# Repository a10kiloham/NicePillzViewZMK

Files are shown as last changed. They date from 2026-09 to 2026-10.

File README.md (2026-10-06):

# Nice Pillz View - ZMK config and PCB

## Overview
ZMK configuration and PCB for the Nice Pillz board, a nice!nano based controller for the Kinesis
Advantage, extended with a nice!view display. Based on https://github.com/nol00p/NicePillz.
The keymap follows the Kinesis Advantage legends and targets Windows.

## Hardware
- The PCB in `kicad/` is updated for the display header and the switch LED, see [PCB](#pcb--ordering-from-jlcpcb) below.
- For the original design and the thumb pads, see https://github.com/nol00p/NicePillz
- For the rubber function buttons replacement with PCB for the older Advantage 1, these are excellent: https://github.com/bluelightning32/kinesis-fn
- `housing_stl/niceview_cover.stl` is a printable cover that holds the nice!view in the Kinesis top shell.

<p>
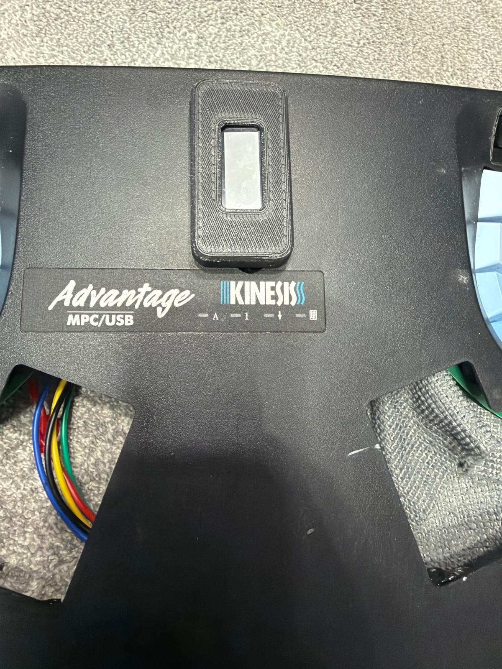
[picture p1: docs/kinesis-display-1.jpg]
nice!view cover fitted in the Kinesis Advantage shell

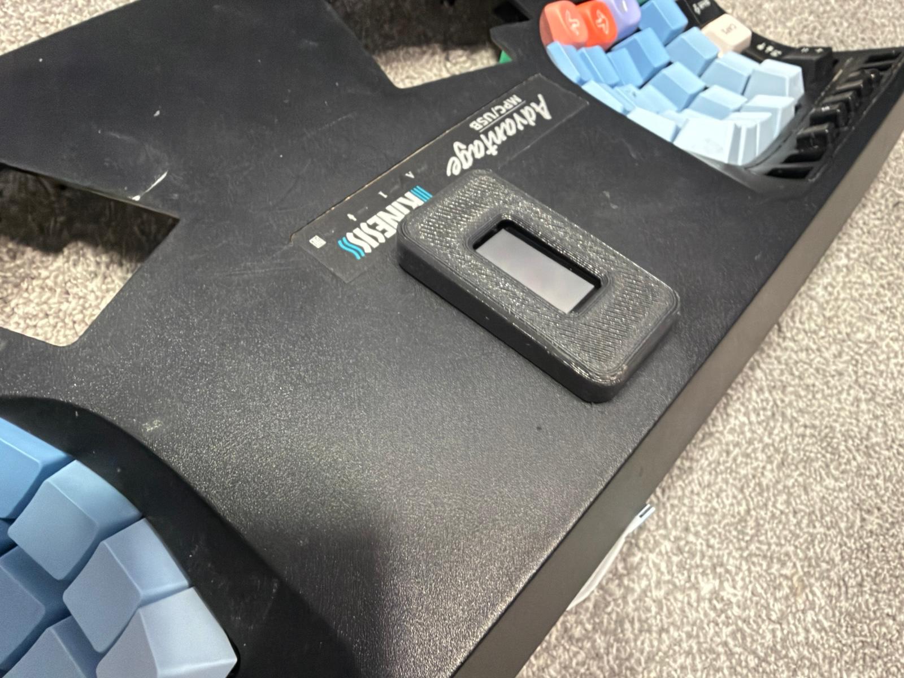
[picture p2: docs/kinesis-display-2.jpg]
nice!view cover, second view

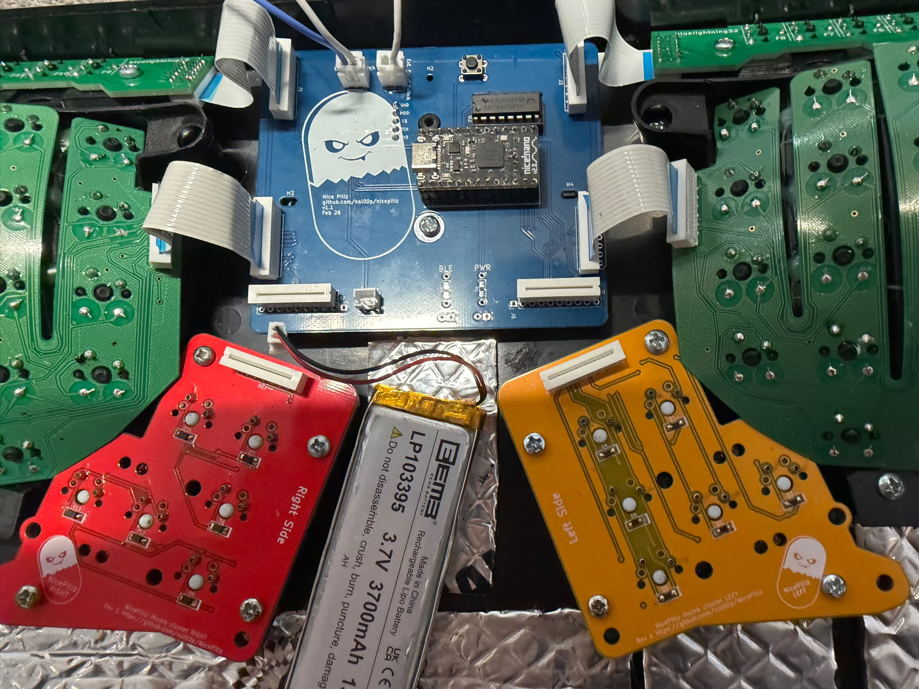
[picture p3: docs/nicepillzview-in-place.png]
Other side

</p>

## Features supported
- [x] ZMK Studio
- [x] nice!view display (vertical): battery/charging, WPM, BT profile, layer, lock indicators
- [x] Leader key
- [x] Caps word
- [x] zmk-helpers
- [x] Layer cycle key
- [x] Macros, with unicode support
- [ ] Combos (supported but not yet tested)

## Quick reference
| Key | Function |
| --- | --- |
| F13 (the Print Screen key) | Unlock ZMK Studio |
| F14 (the Scroll Lock key) | Bluetooth layer, held or tapped before the next key |
| Pause key, right of F14 | Print Screen |
| Keypad key | Layer: steps to the next layer in a loop |
| F14 then 1, 2, 3, 4 | Select Bluetooth profile 1 to 4 |
| F14 then 0 | Toggle the output between Bluetooth and USB |
| F14 then 9, held 3 seconds | Clear the current profile's pairing |
| Program (top right and right thumb) | SYSTEM layer while held |
| Program + Esc or = | Bootloader, for flashing |
| Program + Caps Lock key | Caps Lock |
| Program + left Shift | Leader key |
| Caps Lock key, left side | F5 |
| Key beneath X | Win (GUI) |
| Left thumb, top | Left Ctrl, Alt |
| Right thumb, top | Program, Right Ctrl |
| Left thumb, bottom | Backspace, Delete |
| Right thumb, bottom | Enter, Space |

Notes:

- F13 and F14 are the Print Screen and Scroll Lock positions. Scroll Lock and Pause are not on
  the base layer.
- The Layer key loops through DEFAULT, LOWER, RAISE, FN and KEYPAD, which are dots 1 to 5 on the
  display. SYSTEM and BLUETOOTH are left out of the loop, because they are only meant to be held.
- F13, F14, Print Screen, Layer and Program do the same thing on every layer.
- Left Shift and right Shift are plain Left Shift and Right Shift. Backspace, Delete and Enter are
  plain keys too, so they repeat when held.
- ZMK cannot switch the Bluetooth radio off. F14 then 0 switches the output between Bluetooth and
  USB instead. On battery with USB selected, the keyboard sends nothing.
- F14 then 9 clears only the selected profile. A press shorter than three seconds does nothing.
- LOWER, RAISE and the media-key FN layer are reached with the Layer key.
- The display shows the Bluetooth logo on the left with the profile number beside it at the same
  size. A small tick means connected, a cross means not connected, and no mark means the profile
  is free and advertising.

### Label for the bottom of the keyboard
`docs/bottom-label.txt` fits a 3 x 3 inch label. Print it in a monospace font at 8 pt.

```
NICE PILLZ VIEW - QUICK REFERENCE

TOP RIGHT  F13 Unlock Studio |
  F14 BT | PrtSc | Layer | Program

BLUETOOTH  hold F14 +
  1 2 3 4   select device 1-4
  0         Bluetooth <-> USB
  9 (3 s)   forget this device

SYSTEM     hold Program +
  Esc or =  flash mode (NICENANO)
  Caps key  Caps Lock

LAYER  next layer, loops 1 to 5
  Caps Lock key = F5, under X = Win
  L thumb: Ctrl Alt / Bksp Del
  R thumb: Prog Ctrl / Enter Spc

EDIT KEYS  https://zmk.studio
github.com/a10kiloham/NicePillzViewZMK
```

## Keymap (Windows)
`config/nicepillz.keymap`. The base layer follows the key legends, with these choices:

- Caps Lock position is **F5**. Left Shift is Left Shift and right Shift is Right Shift, both plain keys.
- The letter rows are plain keys, no home-row mods. The key beneath X, left of the Left arrow, is
  **Win**.
- Thumbs: Ctrl, Alt | Program, Ctrl on top; Backspace, Delete | Enter, Space on the big keys, all
  plain keys.
- Top right keys after F12: **Studio unlock** (F13), **Bluetooth** (F14), **Print Screen**,
  **Layer**, **Program**, the same on every layer. Layer steps to the next layer in a loop:
  DEFAULT, LOWER, RAISE, FN, KEYPAD.
- KEYPAD is the numpad layer
  (7 8 9 on U I O, 4 5 6 on J K L, 1 2 3 on M , ., 0 and . on Up/Down, Enter on / and the right
  thumb Enter, Num Lock on 7). The digits follow the Num Lock state, as on any numpad.
  **Program** held = SYSTEM, on both the top right key and the right thumb key.
- **F14** (the Scroll Lock key) is the Bluetooth key, held or tapped before the next key:
  **1-4** select the Bluetooth profile, **0** toggles the output between Bluetooth and USB,
  **9** held for 3 seconds clears the current profile's bond.
- LOWER: F1/F2 previous/next virtual desktop, F3 task view, F4 new desktop, F8 input language,
  F9/F10 move window to the left/right monitor, F11 show desktop, F12 close desktop; arrows on
  H J K L; Ctrl+A/Z/X/C/V on the left hand.
- RAISE: Win+Left/Down/Up/Right on H J K L (snap, restore, maximise, snap), Win+M on U,
  Ctrl+= / Ctrl+- zoom on the number row, ( ) [ ] { } on E R.
- FN: F6 mute, F7 volume down, F8 volume up, F9 previous, F10 play/pause, F11 next, F12 stop.
- SYSTEM (hold Program): **ESC or = = bootloader** (flashing mode), F1-F4 select Bluetooth
  profiles 1-4, F8 clears the current profile's bond, the Caps Lock key is **Caps Lock**, left
  Shift is the **leader** key.

### ZMK Studio
Open [zmk.studio](https://zmk.studio) in Chrome or Edge (Web Serial; Firefox does not work) or the
Studio desktop app, with the keyboard plugged in over USB and running normally, and choose the
`NicePillz` serial device. The keyboard starts locked: press **F13** to unlock, then the keymap
becomes editable. Program+Esc is *not* the Studio key, it reboots into the bootloader for
flashing, and Studio cannot connect while the `NICENANO` drive is showing.
- Leader sequences (hold Program, tap left Shift, then type the sequence): `4` euro sign,
  `D 1`/`D 2` previous/next desktop, `W 1`/`W 2` move window left/right. Unicode macros (accented letters) type through [WinCompose](https://github.com/samhocevar/wincompose),
  which must be installed on the PC.

Keys edited in ZMK Studio are stored on the keyboard and override this file. Flashing a firmware
whose keymap file has changed discards those stored edits automatically on the first boot
(`boards/shields/nicepillz/keymap_rev.c`), so the flashed keymap is always the default. Flashing
the same keymap again keeps the Studio edits; *Restore Stock Settings* in Studio removes them.

## Battery level
Battery reporting is enabled so the level is visible in the OS. Bluetooth and power status update
too for a better experience.

## Display (nice!view)
The board carries a nice!view (Sharp 160x68 memory LCD), mounted vertically with the header pins
at the bottom. The status screen (`boards/shields/nicepillz/view_draw.c`) is drawn upright and
rotated into the panel, top to bottom:

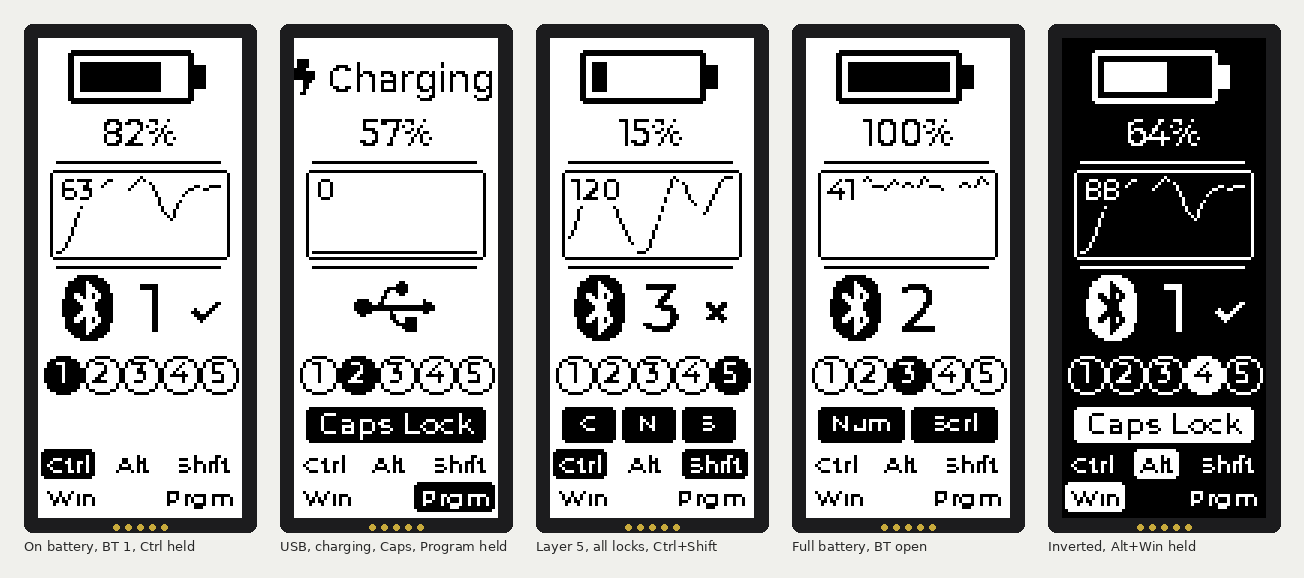
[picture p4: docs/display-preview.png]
display preview


1. **Battery** - a battery-shaped gauge plus the percentage. On USB power the gauge is replaced by
   a lightning bolt and the word *Charging*.
2. **Words per minute** - a graph of the last 24 samples (one every 5 s, so two minutes of
   history, auto-scaled) with the current value in the corner (`CONFIG_NICEPILLZ_WPM_INTERVAL_MS`).
3. **Output** - a Bluetooth logo on the left with the active profile number beside it at the
   same size, then a small tick (connected) or cross (bonded but not connected); a USB symbol
   when USB is the selected output.
4. **Layer** - five numbered dots; the filled one is the highest active layer (1-5).
5. **Lock indicators** - *Caps Lock*, *Num Lock*, *Scrl Lock* boxes in a row, only the active
   ones; they use the host's HID lock state.
6. **Modifiers** - *Ctrl Alt Shift Win Prgm* along the bottom edge; each lights up while the key
   is held. *Prgm* is the Program key, i.e. the SYSTEM layer
   (`CONFIG_NICEPILLZ_PROGRAM_LAYER`).

Options (`boards/shields/nicepillz/Kconfig.defconfig`, override in `boards/shields/nicepillz/nicepillz.conf`):
- `CONFIG_ZMK_DISPLAY=n` disables the display entirely.
- `CONFIG_NICEPILLZ_DISPLAY_INVERTED=y` draws white on black.
- `CONFIG_NICEPILLZ_DISPLAY_LANDSCAPE=y` uses the landscape layout: the picture is turned 90
  degrees clockwise, for a display mounted with the header pins on the right. The same
  elements are rearranged for the 160x68 shape: battery, WPM graph and output on top, layer dots
  and modifiers bottom left, lock indicators bottom right.

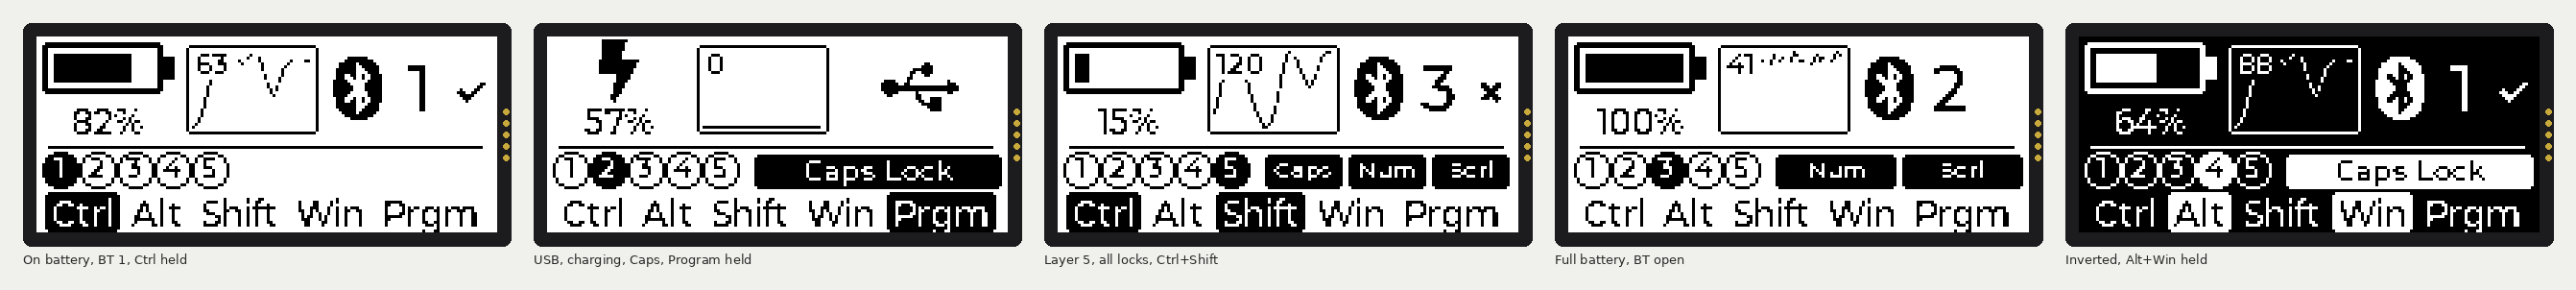
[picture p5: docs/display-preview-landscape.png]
landscape display preview


`tools/preview/build.sh` compiles the real drawing code against LVGL on the host and writes
`docs/display-preview.png`, so layout changes can be checked without flashing.

Wiring: the display shares the SPI bus with the 74HC595 column driver. SCK = P0.11 (D7),
MOSI = P0.24 (D5), display CS = P1.01, powered from the nice!nano VCC pin (switched off in deep
sleep together with the shift register). On v10 boards the J9 header is in the nice!view's own pin
order (CS, GND, 3V3, SCK, MOSI, top to bottom) so the display plugs straight in. v9 boards have J9
as GND, MOSI, CS, SCK, 3V3 and need the display wired pin by pin.

## LEDs and sleep
- **PWR** (D1): on while the board is awake, driven by the spare 74HC595 output (P1.01 is the
  display chip select). Slow flash after 5 min idle, off in deep sleep.
- **BLE** (D2): on while the active Bluetooth profile is connected, off when idle or asleep.
- **Switch LED** header (v10): powers the LED inside an illuminated power switch whenever the board
  has power, see [PCB](#pcb--ordering-from-jlcpcb).

Sleep after 5 min idle: any key resumes. Deep sleep after 20 min: press the Esc key (0,0) to wake.

## PCB / ordering from JLCPCB
`kicad/nice_pillz_niceview_v10.kicad_pcb` is the board (KiCad 10). Ready-to-upload fabrication
files, exported with `kicad-cli` from the committed board (DRC: 0 unconnected items), are in
`kicad/jlcpcb/` and attached to the [v10 release](https://github.com/a10kiloham/NicePillzViewZMK/releases/tag/v10):

- `nice_pillz_niceview_v10_jlcpcb.zip` - upload this as-is to JLCPCB (2 layers, 1.6 mm).
- `gerbers/` - the same files unzipped: copper, mask, paste, silkscreen, board outline (Protel
  extensions), Excellon drills split into PTH / NPTH, and a drill map.

## 

Changes in v10 (silkscreen v1.1) compared with the v9 boards already made:

- **J9 display header** is ordered CS, GND, 3V3, SCK, MOSI to match the nice!view (see Display above).
  Pad numbers and nets are unchanged, so the schematic still matches; only the pad positions inside
  the footprint instance moved (re-importing the footprint from the library would undo this).
- **Switch LED header** replaces the external reset terminal at the top of the board (same two holes).
  It is a 2-pin 2.54 mm header for the LED inside an illuminated power switch: the square pin (marked
  `+`) is the LED anode, fed from the switched 3.3 V rail through **R3** next to it; the round pin is
  GND. Fit R3 to suit the LED: 330 R for red/green/yellow (about 4 mA), 100 R for blue/white. The
  LED is on whenever the keyboard is powered: off when the power switch is off, off in deep sleep
  (the firmware cuts the 3.3 V rail), and on while charging over USB even with the switch off. The
  onboard reset push button is unchanged; there is no longer a terminal for an external reset.
- D1/D2 are labelled LED_PWR / LED_BLE on the fab layer.

## Hardware bill of materials
Mostly common parts and a bit of soldering.

| Position | Part | Qty | Notes |
| --- | --- | --- | ----- |
| J1-J4, J7, J8 | Molex 39-53-2135, 13-way | 6 | [Mouser](https://eu.mouser.com/ProductDetail/Molex/39-53-2135?qs=cm0cgiBciNYI3jeMaEn0Ng%3D%3D) |
| J5, J6 | 1x10 pin header, 2.54 mm | 2 | |
| J9 | nice!view | 1 | v10: plugs onto the header; v9: wire pin by pin |
| | JST-EH 5-pin connector | 2 | display lead |
| | Mill Max 0305 sockets
| U1 | nice!nano v2 | 1 | |
| U2 | 74HC595 | 1 | [Amazon](https://www.amazon.fr/dp/B093Y2MQGV) |
| U2 | Mill Max style connected sockets | 1 | |
| D1, D2 | LED (PWR, BLE) | 2 | [Amazon](https://www.amazon.fr/dp/B005Q2MZ4Q) |
| R1, R2 | 4.7 k resistor | 2 | sets LED brightness, smaller = brighter (1 k is clearly visible at 3.3 V) |
| R3 | 330 R (red/green/yellow) or 100 R (blue/white) | 1 | switch LED series resistor |
| Battery, Ext. PWR Switch | 2-pin screw terminal, 2.54 mm | 2 | v9 boards have a third one for an external reset |
| Switch LED | 1x2 pin header, 2.54 mm | 1 | v10 only |
| | 6 mm tactile reset button | 1 | |
| | Illuminated power switch | 1 | Adafruit; LED leads go to the Switch LED header on v10 |
| | 3.7 V LiPo battery, 2000 mAh | 1 | [Amazon](https://www.amazon.fr/dp/B08214DJLJ) |
| | USB-C panel mount extension | 1 | [AliExpress](https://fr.aliexpress.com/item/1005009401577622.html) |
| | Display cover, 3D printed | 1 | `housing_stl/niceview_cover.stl` |

## 3D Printed Parts
Thanks to `happy panda` for their design here: https://www.printables.com/model/1622734-kinesis-advantage-thumb-millmax-mod
Remixed here if you're using stabilizers: https://www.printables.com/model/1842360-kinesis-thumb-cluster-pcb-replacement-millz-mod-co

## Assembly
A small hot plate (Miniware MHP30 or a cheaper clone) makes the SMD parts much easier.
LED orientation: with the LEDs facing up, the arrow points to the left across the two pads.

## Firmware
GitHub Actions builds the firmware on every push (`build.yaml`). Prebuilt images for the
nice!nano v2 are in `firmware/` and on the release page:

- `nicepillz_nice_nano_v2.uf2` - black on light (default).
- `nicepillz_nice_nano_v2_inverted.uf2` - light on black display (`CONFIG_NICEPILLZ_DISPLAY_INVERTED=y`).
- `nicepillz_nice_nano_v2_landscape.uf2` - landscape display, black on light (`CONFIG_NICEPILLZ_DISPLAY_LANDSCAPE=y`).
- `nicepillz_nice_nano_v2_landscape_inverted.uf2` - landscape display, light on black.
- `settings_reset_nice_nano_v2.uf2` - erases every stored setting: Bluetooth pairings, the keymap
  saved by ZMK Studio, and the selected output.
- `nicepillz_nice_nano_v2_usblog.uf2` and `nicepillz_nice_nano_v2_landscape_usblog.uf2` - the
  portrait and landscape firmware with debug logging over USB, for finding out what the keyboard
  thinks it sent (see below). Slower, use only to debug.

Flash by double-tapping reset and copying the file to the `NICENANO` drive.

To reset the settings entirely, flash `settings_reset_nice_nano_v2.uf2` first. The keyboard does
not type while it is loaded. Then double-tap reset again and flash the normal firmware. Remove the
keyboard from each computer's Bluetooth device list before pairing again.

### Debug logging over USB
Flash `nicepillz_nice_nano_v2_usblog.uf2` (portrait) or `nicepillz_nice_nano_v2_landscape_usblog.uf2`
(landscape), built with `-S zmk-usb-logging` and `CONFIG_ZMK_LOG_LEVEL_DBG=y`. The keyboard then shows up as two serial ports: one is ZMK Studio,
the other streams the log. Open the log port at any baud rate, for example in PowerShell:

```
[System.IO.Ports.SerialPort]::GetPortNames()      # find the new COM port, try each
$p = New-Object System.IO.Ports.SerialPort COM5, 115200; $p.Open()
while ($true) { $l = $p.ReadLine(); if ($l -match "keycode|hold-tap|hold_tap") { $l } }
```

Every key press and release appears as `hid_listener_keycode_pressed ... keycode 0x..`:
0xE0 to 0xE7 are the modifier keys (E0 Left Ctrl, E1 Left Shift, E2 Left Alt, E3 Left Win, E4 to
E7 the right-hand ones). The hold-tap lines name the key position of the few remaining hold-taps
(the Bluetooth layer's 9 key) and say whether they were decided as a hold or a tap, and why.

## Credits
- https://github.com/nol00p/ZMK-NicePillz
- https://github.com/dcpedit/pillzmod
- https://github.com/masters3d/zmk-config-pillzmod-nicenano
- https://github.com/urob/zmk-leader-key
- https://github.com/urob/zmk-helpers

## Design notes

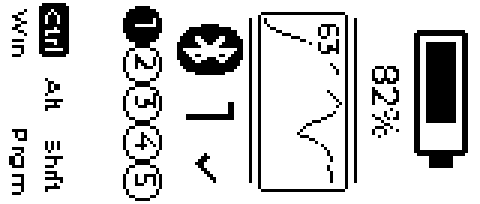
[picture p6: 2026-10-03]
docs/display-panel-raw.png

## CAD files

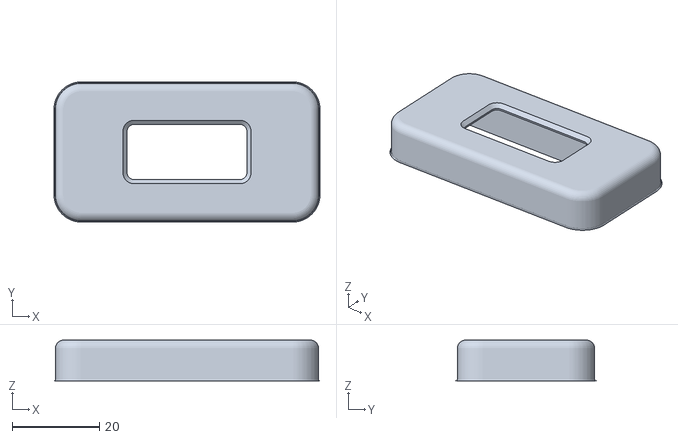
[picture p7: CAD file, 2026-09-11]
housing_stl/niceview_cover.stl
61.1 x 32.2 x 9.39

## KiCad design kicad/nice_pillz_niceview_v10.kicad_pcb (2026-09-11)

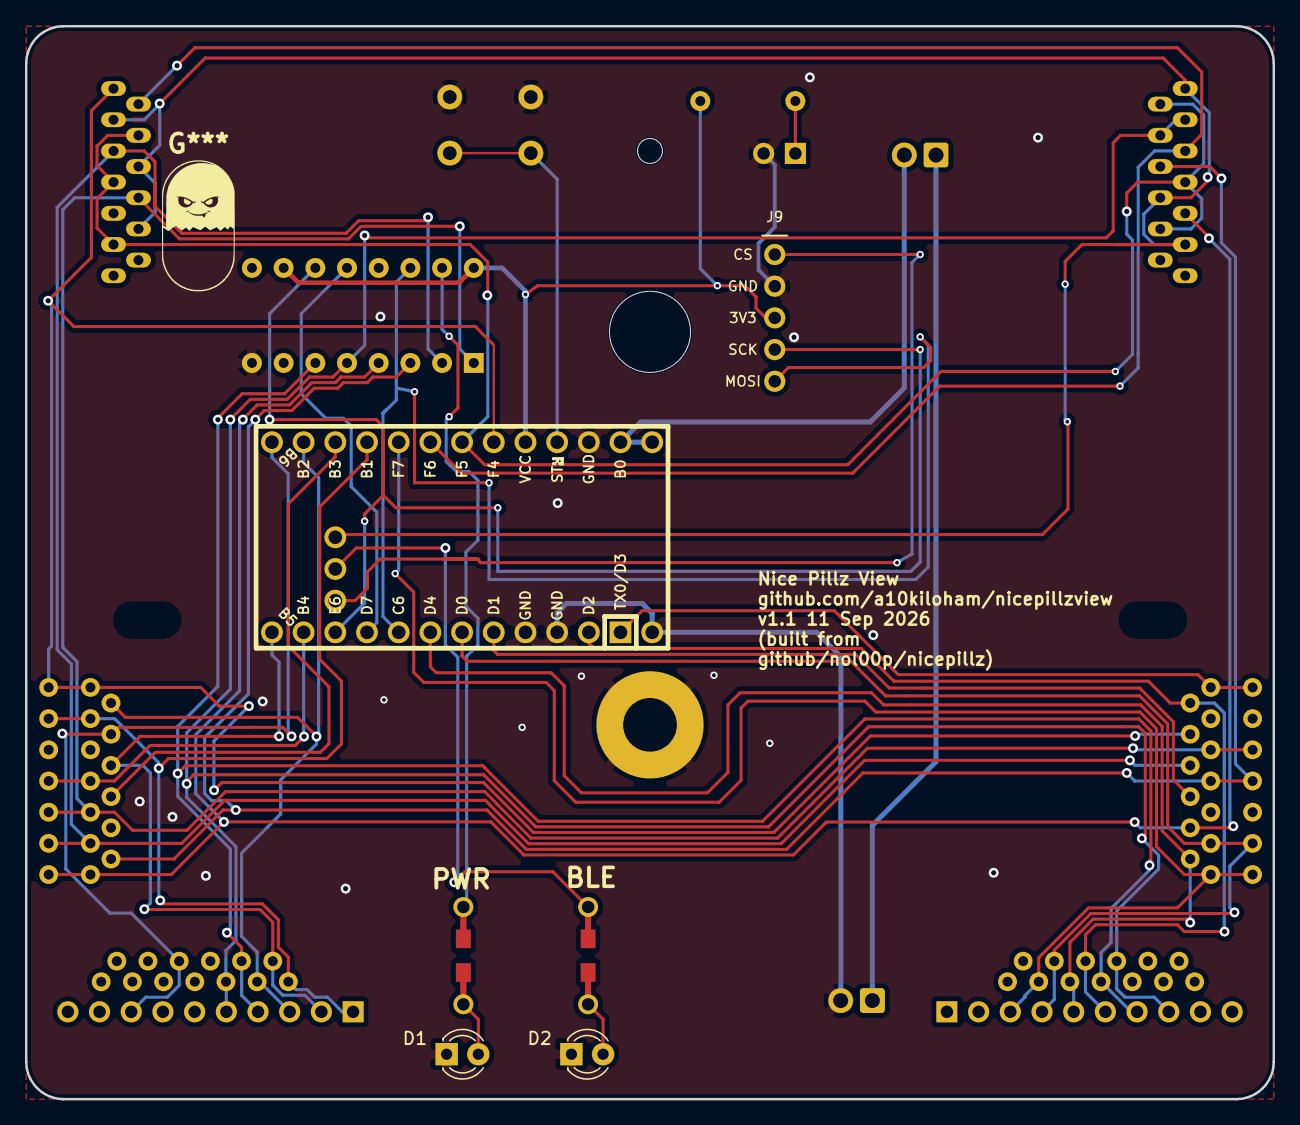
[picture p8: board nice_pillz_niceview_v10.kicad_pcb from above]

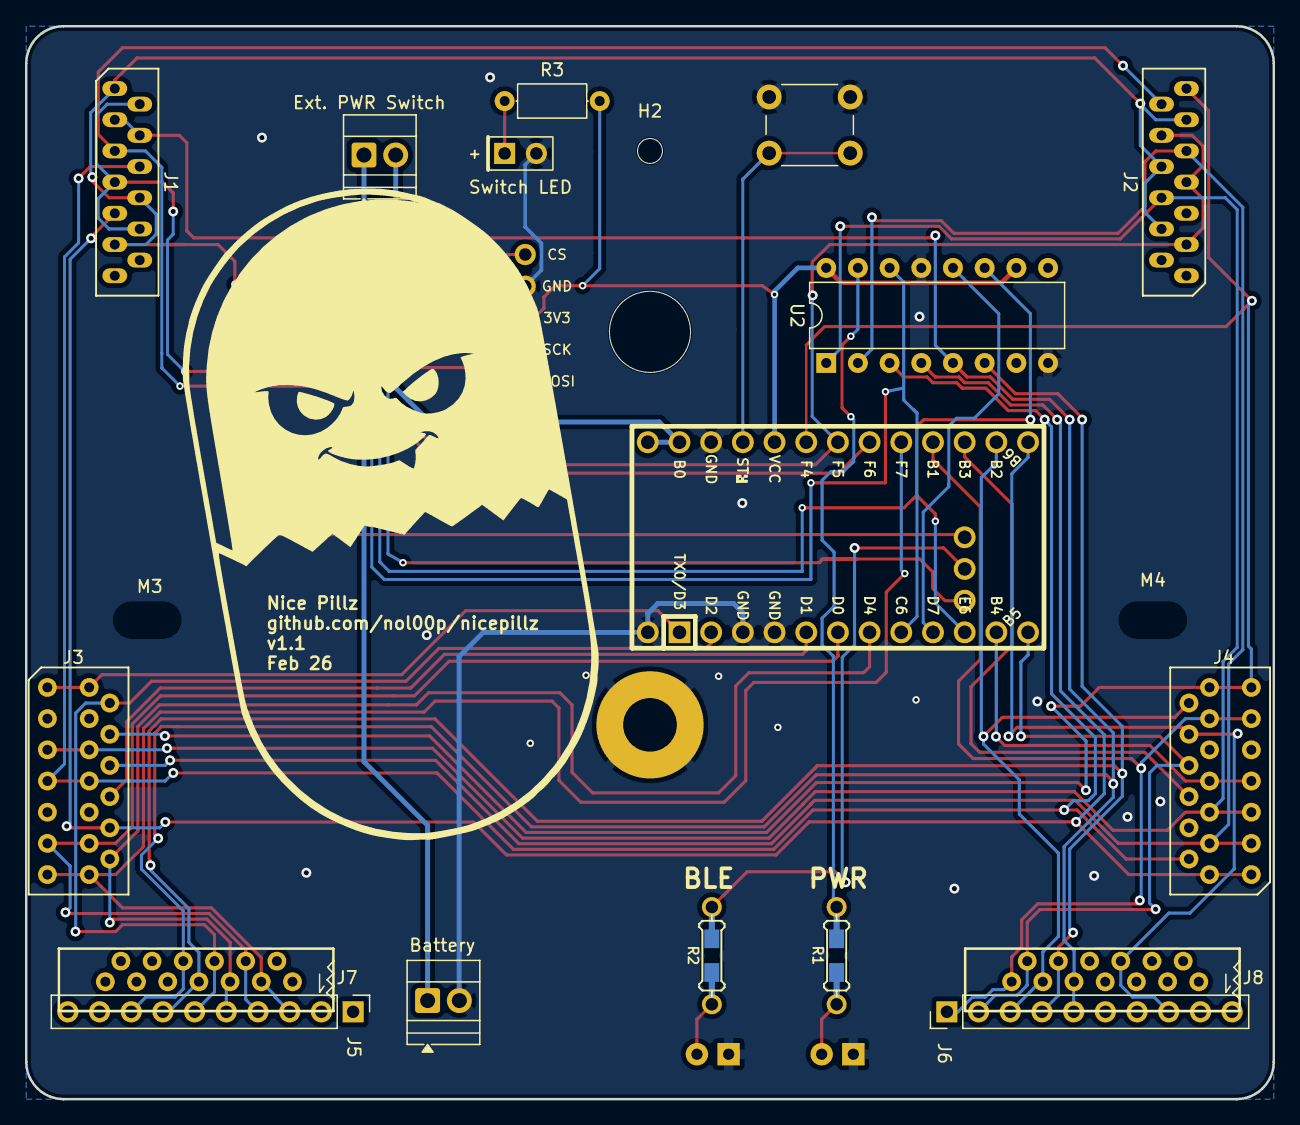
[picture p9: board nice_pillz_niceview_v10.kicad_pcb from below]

Board: 2 copper layers, 100.0 x 86.0 mm, 24 parts (20 on the bottom side), 35 nets.

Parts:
Battery: TerminalBlock_Xinya_XY308-2.54-2P_1x02_P2.54mm_Ho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; TerminalBlock_Xinya_XY308-2.54-2P_1x02_P2.54mm_Horizontal
D1: LED_PWR; LED_D3.0mm
D2: LED_BLE; LED_D3.0mm
Ext. PWR Switch: TerminalBlock_Xinya_XY308-2.54-2P_1x02_P2.54mm_Ho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; TerminalBlock_Xinya_XY308-2.54-2P_1x02_P2.54mm_Horizontal
H1: mounting pad; MountingHole_4.3mm_M4_Pad
H2: mounting pad; MountingHole_2mm
J1, J2: Conn_01x13; Molex_0039532135
J3, J4: Conn_01x13; Molex_039532134
J5, J6: Conn_01x10; Pin_Header_Straight_1x10_Pitch2.54mm
J7, J8: Conn_01x13; 39-53-2135
J9: NiceView; NiceView_1x05_P2.54mm_V
M1: MountingHole_6.4mm_M6
M3, M4: MountingHole_4.3mm_M4
R1, R2: R_US; Resistor-Hybrid
R3: 330R; R_Axial_DIN0207_L6.3mm_D2.5mm_P7.62mm_Horizontal
Switch LED: PinHeader_1x02_P2.54mm_Vertical
U1: nice!nanov2; nice_nano_v2
U2: 74HC595; DIP-16_W7.62mm

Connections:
+5V: J9.5, R3.2, U1.21 (VCC), U2.10 (~SRCLR), U2.16 (VCC)
/COL_0: J2.13, J3.4, J4.13, U1.20 (A3/PF4)
/COL_1: J2.6, J3.5, J4.5, U2.1 (QB)
/COL_2: J2.9, J3.6, J4.3, U2.2 (QC)
/COL_3: J1.6, J3.7, J4.2, U2.3 (QD)
/COL_4: J1.9, J3.10, J4.1, U2.4 (QE)
/COL_5: J1.3, J1.4, J5.8, J6.5, J7.8, J8.9, U2.5 (QF)
/COL_6: J5.7, J6.4, J7.7, J8.10, U2.6 (QG)
/LATCH: U1.9 (6/PD7), U2.12 (RCLK)
/LED_CAPS_LOCK: J9.3, U1.26 (D5)
/LED_NUM_LOCK: R2.2, U1.27 (C7)
/PWR_LED: R1.2, U2.15 (QA)
/ROW_0: J4.6, U1.15 (14/PB3)
/ROW_1: J4.7, U1.11 (8/PB4)
/ROW_2: J4.8, J6.2, J8.12, U1.12 (9/PB5)
/ROW_3: J4.10, J6.8, J8.6, U1.13 (10/PB6)
/ROW_4: J4.11, J6.1, J8.13, U1.16 (15/PB1)
/ROW_5: J4.12, J6.3, J8.11, U1.14 (16/PB2)
/ROW_6: J3.13, J5.3, J7.3, U1.17 (A0/PF7)
/ROW_7: J3.11, J5.4, J7.4, U1.6 (3/PD0)
/ROW_8: J3.12, J5.5, J7.5, U1.7 (4/PD4)
/ROW_9: J3.2, J5.6, J7.6, U1.2 (RX1/PD2)
/ROW_10: J3.1, U1.1 (TX0/PD3)
/ROW_11: J3.8, U1.5 (2/PD1)
/ROW_12: J1.5, J2.12, U1.18 (A1/PF6)
/ROW_13: J1.1, J1.8, J1.11, J2.4, J2.8, J2.11, U1.28 (F1)
/ROW_14: J1.2, J1.7, J1.10, J2.3, J2.7, J2.10, U1.19 (A2/PF5)
/SPI_MOSI: J9.2, U1.8 (5/PC6), U2.14 (SER)
/SPI_SCK: J9.4, U1.10 (7/PE6), U2.11 (SRCLK)
/SW_LED: R3.1, Switch LED.1
BAT: Ext. PWR Switch.2, U1.24 (B0)
BAT+: Battery.1, Ext. PWR Switch.1
GND: Battery.2, D1.1 (K), D2.1 (K), H1.1, J9.1, Switch LED.2, U1.3 (GND), U1.4 (GND), U1.23 (GND), U2.8 (GND), U2.13 (~OE)
unnamed: D1.2 (A), R1.1
unnamed: D2.2 (A), R2.1

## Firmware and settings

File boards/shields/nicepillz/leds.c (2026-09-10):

/*
 * Status LEDs for the Nice Pillz.
 *
 *   led_0 / led-caps : power LED, driven by the 74HC595 output QA
 *   led_1 / led-num  : BLE LED, driven directly by P1.02
 *
 * The 74HC595 is reached over SPI, and its GPIO driver refuses to run from
 * interrupt context (it returns -EWOULDBLOCK). All LED writes are therefore
 * funnelled through a single work item on the system work queue; the idle
 * blink timer only flips a phase flag and queues that work.
 *
 * Behavior:
 *   active : power LED on, BLE LED mirrors the active profile connection
 *   idle   : power LED slow blink (1s on / 2s off), BLE LED off
 *   sleep  : both off
 */

#include <zephyr/device.h>
#include <zephyr/devicetree.h>
#include <zephyr/drivers/led.h>
#include <zephyr/kernel.h>
#include <zephyr/init.h>
#include <zephyr/logging/log.h>

#include <zmk/ble.h>
#include <zmk/activity.h>
#include <zmk/event_manager.h>
#include <zmk/events/ble_active_profile_changed.h>
#include <zmk/events/activity_state_changed.h>

LOG_MODULE_REGISTER(nicepillz_leds, CONFIG_ZMK_LOG_LEVEL);

#define LED_GPIO_NODE_ID DT_COMPAT_GET_ANY_STATUS_OKAY(gpio_leds)

#define LED_PWR DT_NODE_CHILD_IDX(DT_ALIAS(led_caps))
#define LED_BLE DT_NODE_CHILD_IDX(DT_ALIAS(led_num))

/* Idle blink timing */
#define IDLE_BLINK_ON_MS 1000
#define IDLE_BLINK_OFF_MS 2000

static const struct device *led_dev = DEVICE_DT_GET(LED_GPIO_NODE_ID);

static enum zmk_activity_state activity = ZMK_ACTIVITY_ACTIVE;
static bool blink_phase_on;

static void set_led(uint32_t led, bool on) {
    int ret = on ? led_on(led_dev, led) : led_off(led_dev, led);
    if (ret < 0) {
        LOG_WRN("Failed to set LED %u: %d", led, ret);
    }
}

/* --- Apply the LED state for the current activity/BLE state --- */

static void led_update_handler(struct k_work *work) {
    switch (activity) {
    case ZMK_ACTIVITY_ACTIVE:
        set_led(LED_PWR, true);
        set_led(LED_BLE, zmk_ble_active_profile_is_connected());
        break;
    case ZMK_ACTIVITY_IDLE:
        set_led(LED_PWR, blink_phase_on);
        set_led(LED_BLE, false);
        break;
    case ZMK_ACTIVITY_SLEEP:
        set_led(LED_PWR, false);
        set_led(LED_BLE, false);
        break;
    }
}

K_WORK_DEFINE(led_update_work, led_update_handler);

/*
 * Apply immediately when called from a thread (ZMK raises its events from
 * thread context, and on the way to deep sleep there may be no chance for
 * deferred work to run), otherwise defer to the system work queue.
 */
static void led_request_update(void) {
    if (k_is_in_isr()) {
        k_work_submit(&led_update_work);
    } else {
        led_update_handler(NULL);
    }
}

/* --- Idle slow blink timer --- */

static void idle_blink_handler(struct k_timer *timer);
K_TIMER_DEFINE(idle_blink_timer, idle_blink_handler, NULL);

static void idle_blink_handler(struct k_timer *timer) {
    blink_phase_on = !blink_phase_on;
    k_timer_start(&idle_blink_timer,
                  K_MSEC(blink_phase_on ? IDLE_BLINK_ON_MS : IDLE_BLINK_OFF_MS), K_NO_WAIT);
    /* Timer callbacks run in ISR context: never touch the SPI-attached LED here. */
    k_work_submit(&led_update_work);
}

/* --- Activity state listener --- */

static int activity_listener_cb(const zmk_event_t *eh) {
    activity = zmk_activity_get_state();

    if (activity == ZMK_ACTIVITY_IDLE) {
        blink_phase_on = true;
        k_timer_start(&idle_blink_timer, K_MSEC(IDLE_BLINK_ON_MS), K_NO_WAIT);
    } else {
        k_timer_stop(&idle_blink_timer);
    }

    led_request_update();
    return 0;
}

ZMK_LISTENER(activity_led_listener, activity_listener_cb);
ZMK_SUBSCRIPTION(activity_led_listener, zmk_activity_state_changed);

/* --- BLE connection listener --- */

static int ble_listener_cb(const zmk_event_t *eh) {
    /* The handler only mirrors the BLE state while active. */
    led_request_update();
    return 0;
}

ZMK_LISTENER(ble_led_listener, ble_listener_cb);
ZMK_SUBSCRIPTION(ble_led_listener, zmk_ble_active_profile_changed);

/* --- Init --- */

static int leds_init(void) {
    if (!device_is_ready(led_dev)) {
        LOG_ERR("LED device not ready");
        return -ENODEV;
    }

    activity = zmk_activity_get_state();
    led_request_update();

    return 0;
}

SYS_INIT(leds_init, APPLICATION, CONFIG_APPLICATION_INIT_PRIORITY);

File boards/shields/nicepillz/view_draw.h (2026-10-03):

/*
 * Nice Pillz nice!view status screen - drawing module.
 *
 * Pure LVGL, no Zephyr/ZMK dependencies, so the exact same code can be
 * compiled on a host to render previews (see tools/preview/).
 *
 * The screen is designed upright (portrait, 68 wide x 160 tall, pins at the
 * bottom) and drawn into a canvas of that size. npv_rotate() then turns it
 * into the panel's native 160x68 landscape buffer.
 *
 * SPDX-License-Identifier: MIT
 */
#pragma once

#include <lvgl.h>
#include <stdbool.h>
#include <stdint.h>

#define NPV_W 68        /* upright width  */
#define NPV_H 160       /* upright height */
#define NPV_PANEL_W 160 /* panel native width  */
#define NPV_PANEL_H 68  /* panel native height */

enum npv_transport { NPV_TRANSPORT_USB, NPV_TRANSPORT_BLE };

#define NPV_WPM_POINTS 24 /* history shown in the graph, newest last */

#define NPV_MOD_CTRL 0x01
#define NPV_MOD_ALT 0x02
#define NPV_MOD_SHIFT 0x04
#define NPV_MOD_GUI 0x08
#define NPV_MOD_PRGM 0x10 /* the PROGRAM (SYSTEM layer) key is held */

struct npv_state {
    uint8_t battery; /* percent */
    bool charging;   /* USB power present */

    uint16_t wpm;                       /* current value, shown in the graph corner */
    uint8_t wpm_hist[NPV_WPM_POINTS];   /* one sample per update interval */

    uint8_t mods; /* NPV_MOD_* bits: modifier keys and the Program key currently held */

    enum npv_transport transport;
    uint8_t ble_profile; /* 0-based */
    bool ble_connected;
    bool ble_open; /* profile has no bond yet (advertising) */

    uint8_t layer; /* highest active layer, 0-based */

    bool caps_lock;
    bool num_lock;
    bool scroll_lock;

    bool inverted; /* white on black */
};

/* canvas must be NPV_W x NPV_H, LV_IMG_CF_TRUE_COLOR */
void npv_draw(lv_obj_t *canvas, const struct npv_state *st);

/* Landscape layout, drawn for a panel with the header pins on the left. The display is mounted
 * with the pins on the right, so npv_flip() must turn the buffer afterwards.
 * canvas must be NPV_PANEL_W x NPV_PANEL_H, LV_IMG_CF_TRUE_COLOR */
void npv_draw_landscape(lv_obj_t *canvas, const struct npv_state *st);

/* upright: NPV_W*NPV_H pixels, panel: NPV_PANEL_W*NPV_PANEL_H pixels */
void npv_rotate(const lv_color_t *upright, lv_color_t *panel);

/* Turns a NPV_PANEL_W*NPV_PANEL_H panel buffer 180 degrees in place. */
void npv_flip(lv_color_t *panel);

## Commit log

2026-09-10 Add nice!view display support and move power LED to 74HC595
    - Display: Sharp LS0xx (160x68) on the shared SPI bus, CS on P1.01,
    landscape status screen built from stock ZMK widgets: output/BLE
    profile, battery % with charging indicator, active layer, WPM.
    - Power LED now driven by the shift register output QA (v9 PCB);
    LED updates run from thread context since the 595 is SPI-attached.
    - README: display layout, wiring, local Docker build instructions.
2026-09-10 Add KiCad v9 PCB (nice!view variant)
    [nice_pillz_niceview_v9.kicad_pcb]
2026-09-10 PCB: reorder J9 display header to match nice!view pinout
    J9 now reads CS, GND, 3V3, SCK, MOSI top to bottom. Pad numbers and
    nets are unchanged (schematic parity kept); pad positions and silk
    labels moved within the footprint instance and the five connections
    were rerouted. DRC (KiCad 10, zones refilled): no new violations,
    0 unconnected items.
    [nice_pillz_niceview_v9.kicad_pcb]
2026-09-10 Add built firmware images
    nicepillz_nice_nano_v2.uf2: display build (nice!view, WPM, battery)
    nicepillz_nice_nano_v2_usb-logging.uf2: same plus USB serial logging
2026-09-11 Repo cleanup and JLCPCB fabrication files
    - kicad/jlcpcb: Gerbers (Protel ext, mask-subtracted silk), Excellon
    PTH/NPTH drills with maps, and a ready-to-upload zip, generated with
    kicad-cli from the committed board.
    - PCB: remove a dangling ROW_3 track stub (DRC now 74 pre-existing
    warnings/errors, 0 unconnected).
    - Drop stray .DS_Store files, the empty .gitkeep and the per-user
    .kicad_prl; extend .gitignore accordingly.
    - README: ordering / regeneration instructions.
    [nice_pillz_niceview_v9-B_Cu.gbl, nice_pillz_niceview_v9-B_Mask.gbs, nice_pillz_niceview_v9-B_Paste.gbp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]
2026-09-11 Portrait nice!view status screen with clock, WPM, layer dots and lock indicators
    - New status screen drawn upright (68x160) and rotated into the panel so
    it reads with the header pins at the bottom: time, battery gauge + %
    (bolt + "Charging" on USB), WPM (throttled to 5 s), Bluetooth logo with
    profile/state or USB symbol, five numbered layer dots, stacked
    Caps/Num/Scrl Lock indicators from the host HID state.
    - Clock: second USB CDC ACM port; the host writes "T<local epoch>" and
    gets "OK HH:MM" back (scripts/nicepillz-sync-time.sh, udev example in
    the README). Runs from uptime after a sync; cleared by reset/deep sleep.
    - tools/preview: host build of the same drawing code against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
    [main.c, view_draw.h]
2026-09-11 Remove the clock from the status screen
    The keyboard has no time source without a host-side script, so drop the
    time display, the USB time-sync port and the sync script. The battery
    gauge grows into the freed space at the top. Firmware rebuilt (flash 44%,
    RAM 41%); preview PNGs regenerated; README updated (includes the
    battery-section wording fix).
    [main.c, view_draw.h]
2026-09-11 PCB v10: switch LED header replaces the external reset terminal
    Same two holes at the top of the board, now a 1x02 2.54 mm header for the
    LED inside an illuminated power switch: pin 1 (square, "+") is the anode
    fed from the switched 3.3 V rail through new series resistor R3 (330R
    red/green, 100R blue/white), pin 2 is GND. The 3.3 V feed runs on B.Cu
    under COL_5 to a via on the existing rail. The dead RESET branch to the old
    terminal is removed; the reset push button keeps its own link to RST.
    Silkscreen version v1.1; D1/D2 fab values renamed LED_PWR/LED_BLE.
    Project files renamed to v10; JLCPCB Gerbers/drills regenerated.
    DRC: 0 unconnected, no new violations except the two library-mismatch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
    [nice_pillz_niceview_v10-B_Cu.gbl, nice_pillz_niceview_v10-B_Mask.gbs, nice_pillz_niceview_v10-B_Paste.gbp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]
2026-09-11 Regenerate v10 JLCPCB fabrication files
    Fresh export from the committed v10 board; content identical apart from
    generation timestamps.
    [nice_pillz_niceview_v10-B_Cu.gbl, nice_pillz_niceview_v10-B_Mask.gbs, nice_pillz_niceview_v10-B_Paste.gbp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]
2026-09-11 README: merge BOM/assembly branch and tidy
    Brings in the hardware bill of materials, assembly notes and upstream
    credit from the a10kiloham-readme branch, corrected against the v10 board
    (R3, switch LED header, terminal count), drops the Gerber/Docker command
    blocks and the old battery script, adds the display photos and STL cover,
    and fixes anchors and file references.
2026-09-14 Update README
    Added new sections for v10 changes and 3D printed parts.
2026-09-14 Update 3D printed parts section
2026-09-14 Keymap: outer thumb keys are plain Left/Right Control
    They were bound to Super+PageUp / Super+PageDown (GNOME workspace
    switching) although the layout comment labels them CTRL. Both firmware
    images rebuilt.
2026-09-14 Keymap: Windows layout following the Kinesis legends
    - Base layer per the key legends: F9-F12/PrtSc/ScrLk/Pause on the top
    row, arrow keys on the bottom row, Caps Lock position is Tab, DEL/ENTER
    layer-taps, Keypad key toggles a new numpad layer.
    - GNOME workspace shortcuts replaced with Windows equivalents (virtual
    desktops, task view, window snapping, monitor moves, snip, clipboard).
    - Media keys moved to the FN layer; leader sequences updated.
    - Unicode macros switched to Windows (WinCompose).
    - README documents the layers; both firmware images rebuilt.
2026-09-15 Keymap: left Shift is Shift (hold) / leader (tap); document Studio unlock
    The bottom-left key was the leader key only, so Shift was missing on the
    left hand once Studio's stock settings were restored. It is now a balanced
    hold-tap: Shift when held, leader when tapped alone. README explains how
    to connect and unlock ZMK Studio (Program + left Shift), and that
    Program+Esc is the bootloader, not the Studio key. Both images rebuilt.
2026-09-17 Display: WPM history graph and held-modifier row
    - WPM is now a 24-sample graph (one sample per CONFIG_NICEPILLZ_WPM_INTERVAL_MS,
    auto-scaled) with the current value in the corner, replacing the large number.
    - New bottom row shows Ctrl / Alt / Shift / Win, filled while held, from the
    HID explicit modifier state (updates on zmk_modifiers_state_changed).
    - Left Shift hold-tap is hold-preferred so rolling into a key always shifts.
    - Preview harness and README updated; both firmware images rebuilt.
2026-09-27 Keymap: Caps Lock on F13, Print Screen and Layer cycle keys; README quick reference and label
    - Top right keys after F12: Caps Lock, Bluetooth, Print Screen, Layer, Program
    - Layer steps through DEFAULT, LOWER, RAISE, FN, KEYPAD in a loop
    - Remove the LOWER + RAISE = FN conditional layer so the Layer key can select FN
    - README: quick reference table and a 3 x 3 inch label (docs/bottom-label.txt)
    - Rebuilt firmware
    Claude-Session: https://claude.ai/code/session_01NRorwoBSLisdwh3LPH3cmd
2026-10-02 Keymap: plain Delete and Shift keys, Studio unlock on F13
    - The key right of Backspace is a plain Delete, no longer LOWER when held.
    - F13 unlocks ZMK Studio on every layer. Caps Lock moves to Program + the
    Caps Lock key.
    - Left and right Shift are plain LSHFT and RSHFT. The leader key moves to
    Program + left Shift.
    - FN: mute and volume move to F6-F8, so F13, F14 and Print Screen are the
    same on every layer.
    - KEYPAD: the 8 key sends the main =, Windows ignores the keypad = code.
    - SYSTEM: drop the backlight toggle, the board has no backlight.
    - The shield keymap now includes config/nicepillz.keymap instead of
    carrying an old, different layout.
    - Rebuild the firmware images.
    Co-Aut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
2026-10-02 Display: turn the landscape layout 180 degrees
    The landscape layout now suits a display mounted with the header pins on
    the right. The picture is drawn as before and the panel buffer is turned
    180 degrees before it is shown. Rebuild the two landscape firmware images
    and the landscape preview.
    Claude-Session: https://claude.ai/code/session_0127Gs9hugzydTKNHR4wSPeh
2026-10-03 Display: larger modifier row, Prgm indicator, modifiers that update
    - Ctrl Alt Shift Win Prgm is one row in a 12 px font in landscape (two 8 px
    rows in portrait). Prgm lights while the Program key holds the SYSTEM
    layer (CONFIG_NICEPILLZ_PROGRAM_LAYER).
    - The modifiers never updated: ZMK does not raise
    zmk_modifiers_state_changed. Track the modifier keys from the keycode
    events instead.
    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
2026-10-06 Add a landscape firmware with USB debug logging
    For tracing phantom modifier presses: every keycode and every hold-tap
    decision goes out over a second USB serial port. README explains how to
    read it from PowerShell.
    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
2026-10-11 Keymap: Bluetooth on Program + F1-F4 / F8, Shift + F14 toggles the output
    - Program + F1 to F4 select Bluetooth profile 1 to 4.
    - Program + F8 forgets all four Bluetooth pairings (BT_CLR_ALL).
    - F14 is a plain F14; Shift + F14 switches the output between Bluetooth
    and USB (mod-morph).
    - The BLUETOOTH sticky layer and the 3 s hold-to-clear key are gone.
    - Rebuild all firmware images; update README and the bottom label.
    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
2026-10-11 Add KEYS.md, a one-page key reference for printing
    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
2026-10-11 Settings reset firmware that keeps the keyboard and display working
    Replace the bare settings_reset shield image with the normal firmware
    built with CONFIG_ZMK_SETTINGS_RESET_ON_START=y, portrait and landscape.
    The old image had no keymap and no display driver, so the screen showed
    noise and nothing typed while it was loaded.
    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
2026-10-14 KEYS.md: say where the reset button and the reset firmware are
    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
